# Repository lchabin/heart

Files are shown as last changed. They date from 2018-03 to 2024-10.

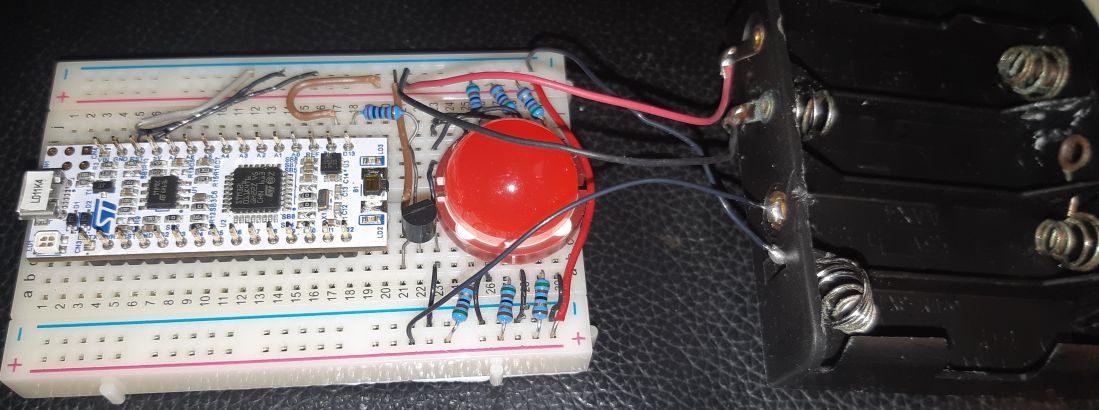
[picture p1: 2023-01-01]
doc/heart_beating.jpg

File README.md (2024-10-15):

# Red Beating Heart every Saint Valentin For the whole day. 
Proven 4 years autonomy with 2x2AA alcaline batteries.
On NUCLEO-L011K4

## Battery Autonomy
This design has been running non stop from March 17th 2018 to the end of 2022 on 4 AA alcaline batteries 
Configured to generate a pulse every hour (rather acceptable for the battery).
It has successfully generated heart beats every Saint Valentin of 2019,2020,2021,2022
The batteries were changed in Dec. 2022. 

Used this configuration in 2018:

$13h20m00s04w03m17d18y03600wkup

See below for explanations.

Used this configuration:

$17h14m00s06w12m31d22y03600wkup

## USING THE DESIGN WITH JUST THE NUCLEO BOARD : just to take a look, flash the board (program it) and make some tests

You can check the firmware and functionality before making the cicuit : 

Because it happens that PB3/D13 (GPIO of the nucleo board) also drives the green led of the nucleo board, you can test the functionality with the nucleo board as it is out of the factory. 
(no resistor, no transistor, no battery, with solder bridges SB14 and SB9 still closed, no big red led, no breadboard).

### Flashing (programming)
+ ensure no battery is connected
+ ensure SB14 and SB9 are closed
+ connect usb to a pc
+ flash using STM32CubeProg available from www.st.com 
(don't need the trusted package thing). 
+ You flash program the file MDK-ARM/heart/heart.hex
+ stop STM32CubeProg
### Settings and run
+ ensure no battery is connected
+ ensure SB14 is closed
+ start a terminal ('tera term' for instance) at 4800 bauds 
+ configure the terminal at 4800 bauds 
+ connect usb to a pc 
+ open connection to the new serial port in tera term
+ follow the instructions (displayed every 10 sec, with a led pulse)
Then it runs

## USING THE DESIGN ON BATTERY : the real deal
That's the only way to have it running for years.

### Prepare the NUCLEO board : REQUIRED ! 
See doc/open_sb14_sb9.png : open SB14 and SB9 solder bridges on the bottom on the nucleo board (voltage conflict, and reset).

From that moment, never connect anymore usb without the 3V battery holders connected to 3.3V first

Once SB9 is open, programming of the nucleo _may_ be a little more difficult (might fail more often), but i am not sure of that.  

### Flashing (programming) if not already done. RESPECT THAT SEQUENCE
+ ensure SB14 is open
+ connect battery to +3V3 pin and GND pin
+ connect usb to a pc
+ flash using STM32CubeProg available from www.st.com 
(don't need the trusted package thing).
+ You flash program the file heart.hex
+ stop STM32CubeProg
+ disconnect usb (clean fast disconnection)

### Settings and run. RESPECT THAT SEQUENCE
+ ensure SB14 and SB9 are open
+ start a terminal ('tera term' for instance) at 4800 bauds 
+ configure the terminal at 4800 bauds 
+ connect battery to +3V3 pin and GND pin
+ connect usb to a pc 
+ open connection to new serial port in tera term
+ follow instructions (displayed every 10 sec, with a led pulse)
+ disconnect usb (clean fast disconnection), voilà !

Once SB14 is open, Never connect usb without battery connected.

To restart the setting phase, you need to disconnect the battery then reconnect it (if a reset with the little push button on the side of the pcb is not enough).

## TRYING some tests

Examples (not in TESTING mode, nominal, heart.hex as on github)

### it is 1:20pm on thursday 15 march 2018

$13h20m00s04w03m15d18y00000wkup

+ will pulse on next saint valentin in 11 months, for 18 hours, then next year... 
+ one heart beat pulse every midnight
+ no wake up pulses

nota : monday is 01w

### it is 5:59pm on thursday 14 feb 2019

$17h59m00s04w02m14d19y00000wkup

+ will pulse on next saint valentin in one minute, for 18 hours, then next year.
+ one heart beat pulse every midnight
+ no wake up pulses

### it is 5:50pm on thursday 14 feb 2019

$17h50m00s04w02m14d19y03600wkup

+ will pulse on next saint valentin in ten minutes, for 18 hours, then next year.
+ one heart beat pulse every midnight
+ one wake up short pulse (150ms) every 3600 seconds  (just ok for the battery, help ensure it works)

## Touble shooting

if the red led flashes every 10 sec, that means that it is still waiting for a configuration to be given to it

using '03600wkup' in the config, helps check after one hour that it is really working 

## normal behaviour of the board

after a power on start up, 

+ the board does a 3 seconds fast pulse train
+ then it waits for the configuration information

Example of the text displayed:
```
You are in final target mode

Please write (or paste) the time and wake up delay. Don't use del,backspace because it is ignored
Example :
$21h24m00s05w03m09d18y00060wkup
Format : hour, minute, second, weekday, month, day of the month, year, wakeupEvery in seconds from 1 to 65535 (0 for no wake up). 01w == monday
$19h36m00s06w12m31d22y0360wkup
Setting time to $19h36m00s06w12m31d22y03600wkup
You can now disconnect usb.
```

+ just after configuration, it produces again a 3 seconds fast pulse train
+ there is then a 3 seconds delay, 
+ then, it produces again a 3 seconds fast pulse train
+ then it goes into deep sleep (standby) until the next wake up, midnight or saint valentin.

I would recommend that you disconnect USB during these 9 seconds of post configuration

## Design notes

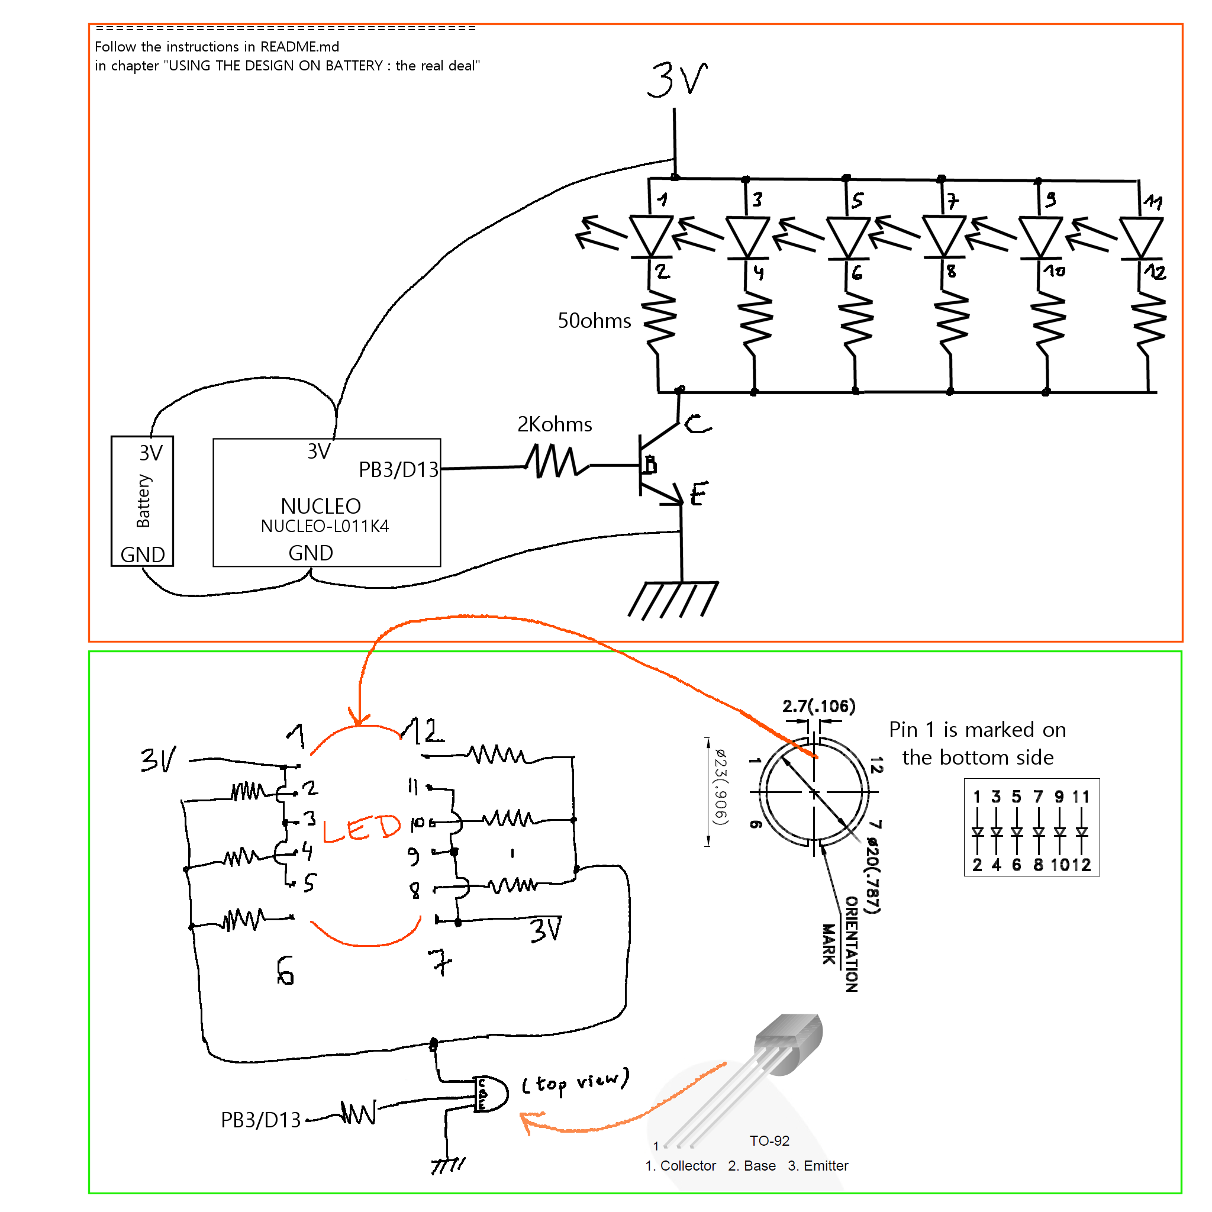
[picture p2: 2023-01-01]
doc/schematic.png

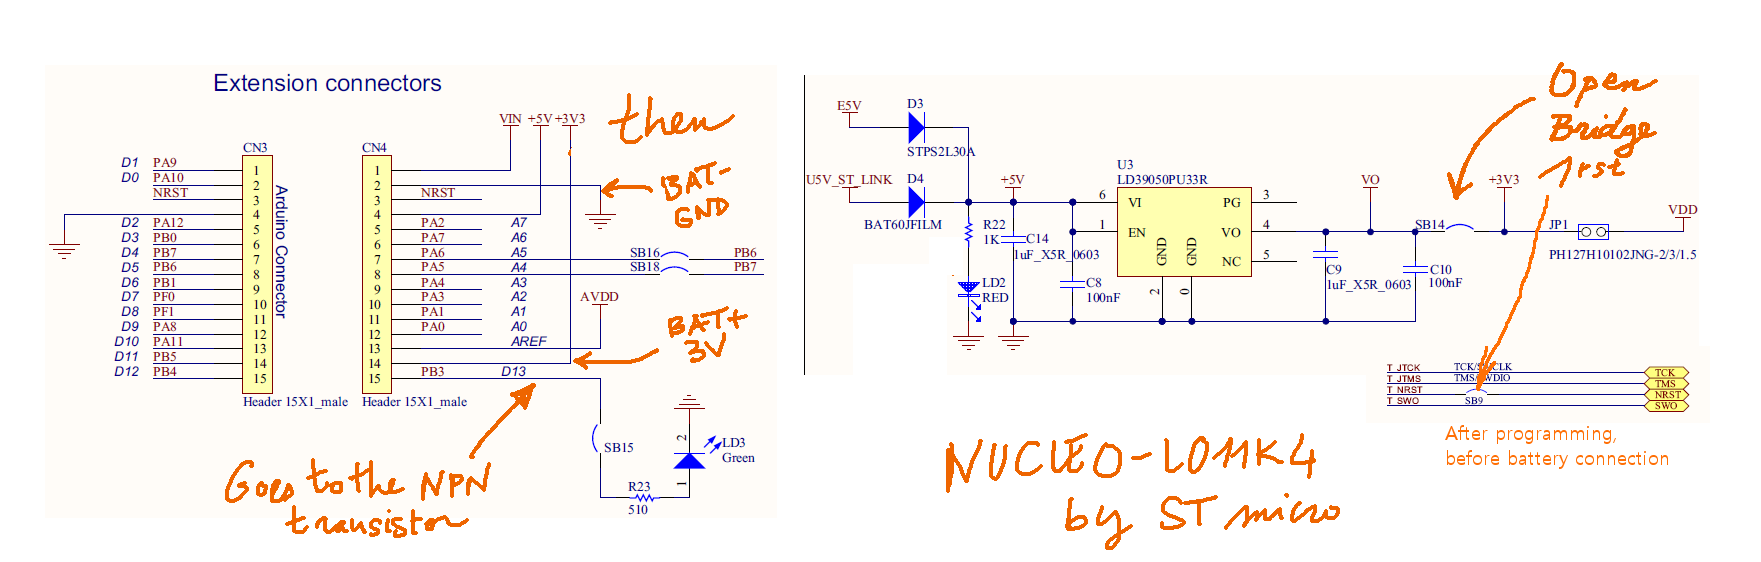
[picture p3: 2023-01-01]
doc/nucleo.png

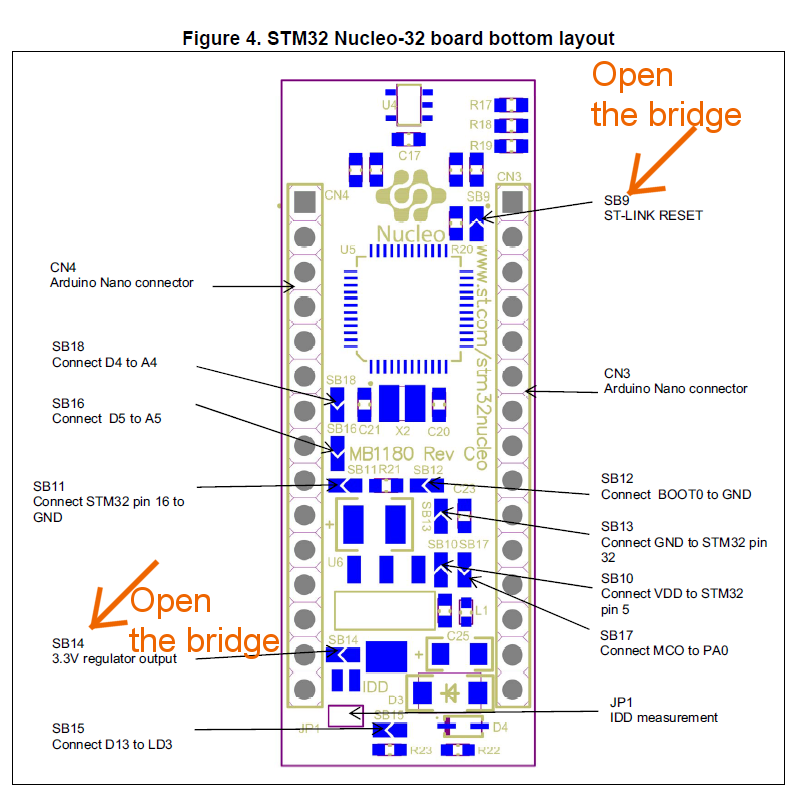
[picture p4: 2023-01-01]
doc/open_sb14_sb9.png

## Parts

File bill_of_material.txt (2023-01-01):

Bill of material 

USE ONLY ALCALINE 1.5V batteries, 
Get 4 batteries, new from the same pack. This is to ensure the same voltages because we are going to put them in parallel.

DO NOT USE ACCUMULATORS NiMH (1.2V), we need 1.5V during the programming phase else too large a voltage difference between 3.3V from USB and 2*Vbat

Farnell farnell.fr , farnell.com, www.newark.com references

03.530€ 1x 2146419 DLA/6SRD - LED, Basse puissance, Rouge, Traversant, 20mm, 20 mA, 1.85 V, 640 nm
03.230€ 1x 2395961 MCBB400 -  Carte prototypage, sans soudure, ABS (Acrylonitrile Butadiène Styrène), 8.3mm, 54.5mm x 83.5mm
01.200€ 2x 1702631 2463    -  Support batterie, AA x 2, à fils
11.000€ 1x 2535699 NUCLEO-L011K4 -  Carte de développement, STM32L011K4 MCU, Débogueur sur la carte, Compatible Arduino Nano
05.070€ 1x 817363  pack of four AA Alcaline Batteries 
00.148€ 1x 2453790 BC547BTF -  Transistor simple bipolaire (BJT), NPN, 45 V, 300 MHz, 500 mW, 100 mA, 200 hFE (per 5)
00.053€ 1x 2329911 TE CONNECTIVITY - Résistance traversante, 2 kohm, Série LR, 200 V, Couche métallique, Axial, 250 mW (per 10)
00.053€ 1x 2329951 TE CONNECTIVITY - Résistance traversante, 51 ohm, Série LR, 200 V, Couche métallique, Axial, 250 mW (per 10)

Some wire, for example if you have nothing (it is a rigid core, single conductor)
14.610€ 1 x 2290875 - 3050/1 WH005 -  Câble, Rigide, Hook Up, PVC (Chlorure de polyvinyle), Blanc, 24 AWG, 0.205 mm², 100 ft, 30.5 m
or much thinner and flexible, harder to strip and insert cause small:
14.500€ 1 x 1183994 - SPC00440A002 25M -  Câble, PTFE (Polytétrafluoroéthylène), Noir, 26 AWG, 0.128 mm², 82 ft, 25 m

One micro USB cable

6x 50 ohms resistors will limit current on each led to about 20mA
1x 2K ohms resistor from cpu PB3/D13 pin to base of transistor

an iron (just to open the SB14 and SB9 solder bridges on the nucleo board)

======================================
Justification for the values of the resistors

Current in the leds ? We want 0.02A current in each of the 6 leds total 0.120A, at ~1.85V.

Checking that the transistor will be able to drive the leds in good saturation
We have in datasheet NPN : hFE = 200.
Ibase = (3-0.6)/2000 = 0.0012A 
Icollector = 1.2mA*hFE = 0.240A. OK > 0.120A
OK

What resistor to put in series with the leds for that ?
BC547BTF Saturation voltage at 0.12A ~= 0.15v to 0.2v
which leads to a resistance for each led of R = U/I = (3-0.15-1.85)/0.02 = 50 ohms.

I think it would not be recommended to put all the leds in parallel with a single 8.3333 ohm resistor because of the variations in production, but it should rather work. Would still be below 1/4w
But that would make less wires.

======================================
Checking the firmware and functionality before assembly on the breadboard

Because it happens that PB3/D13 also drives the green led of the nucleo board, you can test the functionality with the nucleo board as it is out of the factory. 
(no resistor, no transistor, no battery, with SB14 and SB9 still closed, no big led, no breadboard).

======================================
To build the circuit with the breadboard, the components and wires:
See doc/schematic.png
See doc/nucleo.png
See doc/open_sb14_sb9.png
Ask if you have no idea how to do that.

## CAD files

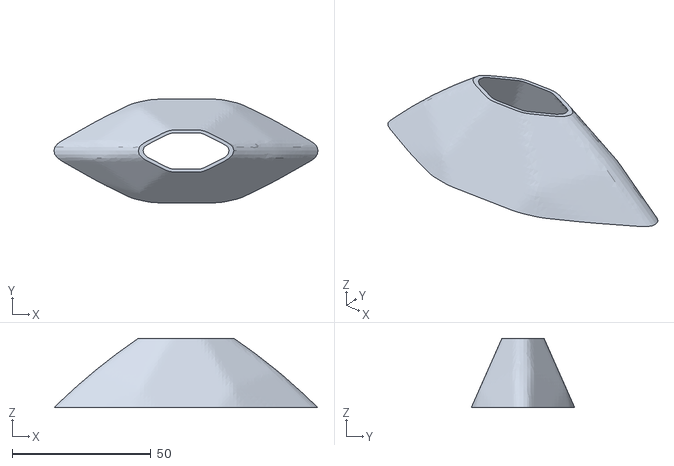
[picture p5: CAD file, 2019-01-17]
3d/support_pet_coeur.stl
95.3 x 37.4 x 25.0

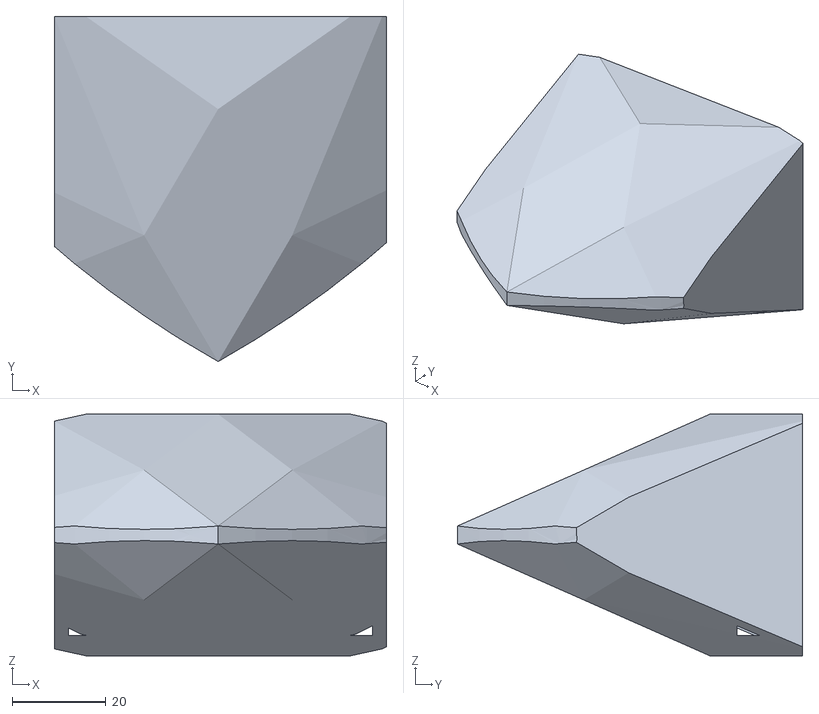
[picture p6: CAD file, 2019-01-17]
3d/support_elec.stl
71.0 x 73.8 x 51.7

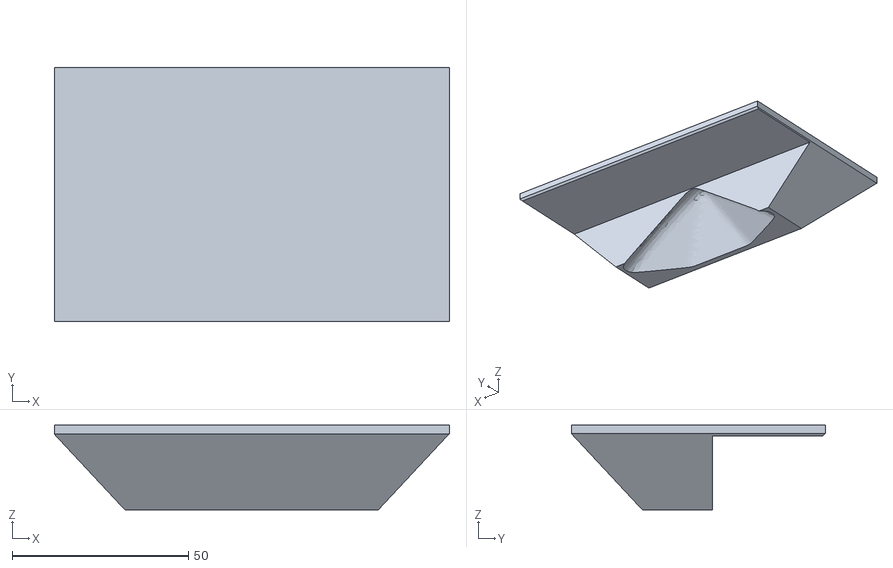
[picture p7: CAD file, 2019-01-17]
3d/support_coeur.stl
112.0 x 72.0 x 24.0

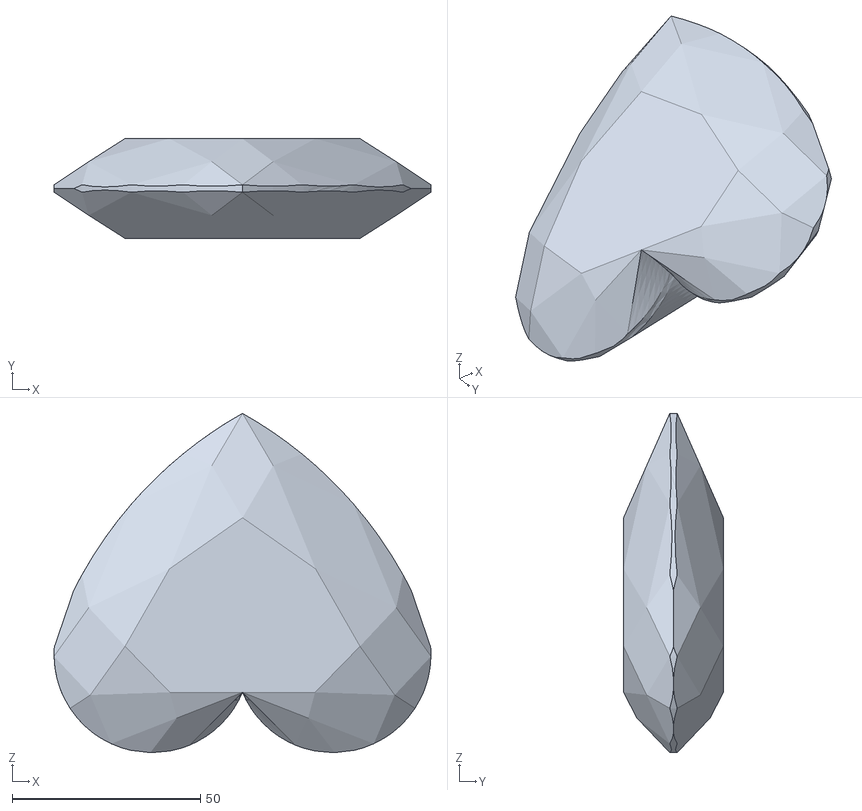
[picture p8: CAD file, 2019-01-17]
3d/Heart-shaped-Gem.stl
100.0 x 26.5 x 90.0

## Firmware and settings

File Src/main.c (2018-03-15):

/**
  ******************************************************************************
  * @file           : main.c
  * @brief          : Main program body
  ******************************************************************************
  ** This notice applies to any and all portions of this file
  * that are not between comment pairs USER CODE BEGIN and
  * USER CODE END. Other portions of this file, whether 
  * inserted by the user or by software development tools
  * are owned by their respective copyright owners.
  *
  * COPYRIGHT(c) 2018 STMicroelectronics
  *
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
  ******************************************************************************
  */
/* Includes ------------------------------------------------------------------*/
#include "main.h"
#include "stm32l0xx_hal.h"

/* USER CODE BEGIN Includes */
#include "stm32l0xx_hal_rtc.h"
#include "led.h"
#include "set_time.h"
/* USER CODE END Includes */

RTC_HandleTypeDef hrtc;

UART_HandleTypeDef huart2;

/* USER CODE BEGIN PV */

/* USER CODE END PV */

void SystemClock_Config(void);
static void MX_GPIO_Init(void);

/* USER CODE BEGIN PFP */

/* USER CODE END PFP */

/* USER CODE BEGIN 0 */

// Even with a quartz 32.768Khz, the clock will drift a lot over the years
// You might measure luminosity (with some electronics and code) and steer RTC to follow the daylight to compensate drift for years
// your code here
// Will be called every "wakeupEvery"
// but I think that 20ppm is enough : only 1.75 hours shift in 10 years... OK.
// 24h*365.25*10*20e-6 = 1.75h
void wakeupStep(void)
{
		ledOn();
		HAL_Delay(150);
		ledOff();	
}

void daylyStep(void)
{
		ledPulse();
}

// TESTING can be defined in the project properties.
// Remove it when done.
// Run Beating Heart for ... seconds
#ifdef TESTING
#define SECONDS_BEATING_HEART  120 
#define RTC_MONTH_SELECTED RTC_MONTH_MARCH
#else
// beating heart for 18 hours :  3600*18
#define SECONDS_BEATING_HEART  (3600*18)
// saint valentin is in february
#define RTC_MONTH_SELECTED RTC_MONTH_FEBRUARY
#endif

void saintValentin(void)
{
	for (int i=0;i<SECONDS_BEATING_HEART ;i++)
		heartBeatOneSecond();
}

uint8_t g_saintValentin;
uint8_t g_wakeUp;
uint8_t g_dailyAlarm;

// Default config that will be written if nothing sent after 100secs on the serial port
// Useful in dev phase, we don't need to have a complex setup 
// But when on battery 3V, will need to use the serial port 
uint8_t clock_time[] = "23h59m00s06w03m09d18y00120wkup"; // 30+1 for a 0x00 terminated char inserted by the compilator, but not required to have one

/* USER CODE END 0 */

/**
  * @brief  The application entry point.
  *
  * @retval None
  */
int main(void)
{
  /* USER CODE BEGIN 1 */
	uint32_t tickstart;
	RTC_DateTypeDef sDate1;
	RTC_DateTypeDef sDate2;
	uint8_t outOfStandby;
  /* USER CODE END 1 */

  /* MCU Configuration----------------------------------------------------------*/

  /* Reset of all peripherals, Initializes the Flash interface and the Systick. */
  HAL_Init();

  /* USER CODE BEGIN Init */
// WE DONT CALL MX_RTC_Init(), we run our own code
  /* USER CODE END Init */

  /* Configure the system clock */
  SystemClock_Config();

  /* Initialize all configured peripherals */
  MX_GPIO_Init();
  /* USER CODE BEGIN 2 */
	
	HAL_PWREx_EnableLowPowerRunMode();
	
	hrtc.Instance = RTC;
	
	if (PWR->CSR & PWR_CSR_SBF) 
	{
		outOfStandby = true;	// We come back from standby
		PWR->CR |= PWR_CR_CSBF; // reset bit.  
	}
	else
		outOfStandby = false;

  /* USER CODE END 2 */

  /* Infinite loop */
  /* USER CODE BEGIN WHILE */
  while (1) 
  {
		g_saintValentin = false; // XXXXXX  Put a breakpoint here, debug, run, breakpoint, reset, remove breakpoint then run to debug the setup code 
		g_wakeUp = false;
		g_dailyAlarm = false;

		// Identify the cause of Interrupt, and reset int flag 
		
		if (__HAL_RTC_WAKEUPTIMER_GET_FLAG(&hrtc,RTC_ISR_WUTF)) // by WAKE UP
		{
			/* Disable the write protection for RTC registers */
			__HAL_RTC_WRITEPROTECTION_DISABLE(&hrtc);
			__HAL_RTC_WAKEUPTIMER_DISABLE(&hrtc);
			__HAL_RTC_WAKEUPTIMER_CLEAR_FLAG(&hrtc, RTC_FLAG_WUTF);
			tickstart = HAL_GetTick();
			/* Wait till RTC ALRAWF flag is set and if Time out is reached exit */
			while(__HAL_RTC_WAKEUPTIMER_GET_FLAG(&hrtc, RTC_ISR_WUTWF) == RESET)
			{
				if((HAL_GetTick() - tickstart ) > RTC_TIMEOUT_VALUE)
				{
					/* Enable the write protection for RTC registers */
					__HAL_RTC_WRITEPROTECTION_ENABLE(&hrtc);
					crash(1);
				}
			}
			__HAL_RTC_WAKEUPTIMER_ENABLE(&hrtc);
			/* Enable the write protection for RTC registers */
			__HAL_RTC_WRITEPROTECTION_ENABLE(&hrtc);
			
			g_wakeUp = true;
		}

		// Identify the cause of Interrupt, and reset int flag 
		
		if (__HAL_RTC_ALARM_GET_FLAG(&hrtc,RTC_ISR_ALRAF)) // By ALARM A
		{
				/* Disable the write protection for RTC registers */
				__HAL_RTC_WRITEPROTECTION_DISABLE(&hrtc);
				__HAL_RTC_ALARMA_DISABLE(&hrtc);
				__HAL_RTC_ALARM_CLEAR_FLAG(&hrtc, RTC_FLAG_ALRAF);
				tickstart = HAL_GetTick();
				/* Wait till RTC ALRAWF flag is set and if Time out is reached exit */
				while(__HAL_RTC_ALARM_GET_FLAG(&hrtc, RTC_FLAG_ALRAWF) == RESET)
				{
					if((HAL_GetTick() - tickstart ) > RTC_TIMEOUT_VALUE)
					{
						/* Enable the write protection for RTC registers */
						__HAL_RTC_WRITEPROTECTION_ENABLE(&hrtc);					
						crash(2);
					}
				}
				__HAL_RTC_ALARMA_ENABLE(&hrtc);
				/* Enable the write protection for RTC registers */
				__HAL_RTC_WRITEPROTECTION_ENABLE(&hrtc);

// APB1 Clock = 131Khz < 7*32.768Khz
/*
To be able to read the RTC calendar register when the APB1 clock frequency is less than
seven times the RTC clock frequency (7*RTCLCK), the software must read the calendar
time and date registers twice.
If the second read of the RTC_TR gives the same result as the first read, this ensures that
the data is correct. Otherwise a third read access must be done.
*/		
				
			HAL_RTC_GetDate(&hrtc, &sDate1, RTC_FORMAT_BCD);
			HAL_RTC_GetDate(&hrtc, &sDate2, RTC_FORMAT_BCD);
			if (sDate1.Month!=sDate2.Month)
			{
				HAL_RTC_GetDate(&hrtc, &sDate1, RTC_FORMAT_BCD);
			}
				
			if (sDate1.Month==RTC_MONTH_SELECTED)
				g_saintValentin = true;
		}

		// Identify the cause of Interrupt, and reset int flag 
		
		if (__HAL_RTC_ALARM_GET_FLAG(&hrtc,RTC_ISR_ALRBF)) // By ALARM B
		{
				/* Disable the write protection for RTC registers */
				__HAL_RTC_WRITEPROTECTION_DISABLE(&hrtc);
				__HAL_RTC_ALARMB_DISABLE(&hrtc);
				__HAL_RTC_ALARM_CLEAR_FLAG(&hrtc, RTC_FLAG_ALRBF);
				tickstart = HAL_GetTick();
				/* Wait till RTC ALRBWF flag is set and if Time out is reached exit */
				while(__HAL_RTC_ALARM_GET_FLAG(&hrtc, RTC_FLAG_ALRBWF) == RESET)
				{
					if((HAL_GetTick() - tickstart ) > RTC_TIMEOUT_VALUE)
					{
						/* Enable the write protection for RTC registers */
						__HAL_RTC_WRITEPROTECTION_ENABLE(&hrtc);					
						crash(9);
					}
				}
				__HAL_RTC_ALARMB_ENABLE(&hrtc);
				/* Enable the write protection for RTC registers */
				__HAL_RTC_WRITEPROTECTION_ENABLE(&hrtc);

				g_dailyAlarm = true;
		}
		
		
		
		if (outOfStandby) // We come back from standby
		{
			// Process interrupts
			if (g_wakeUp)
			{
				wakeupStep();
			}
			if (g_dailyAlarm)
			{
				daylyStep();
			}
			if (g_saintValentin)
			{
				saintValentin();
			}
		}
		else // this is a power on startup : setup code : get time by serial port or set it to some default value (for tests)
		{ 
			pulseTrain3s();  
			HAL_Delay(3000);

			getConfigByComPort(clock_time,sizeof(clock_time)-1);
			
			__HAL_RTC_WRITEPROTECTION_DISABLE(&hrtc);
			__HAL_RTC_WAKEUPTIMER_DISABLE(&hrtc); // necessary  ? 
			__HAL_RTC_ALARMA_DISABLE(&hrtc);
			__HAL_RTC_ALARMB_DISABLE(&hrtc);
			__HAL_RTC_WRITEPROTECTION_ENABLE(&hrtc);

			RTC_Init_Time_and_Date(clock_time);
			RTC_Set_Enable_WakeUp_AlarmAB(clock_time);
			pulseTrain3s();
			HAL_Delay(3000);
			pulseTrain3s();
		}
/*
	DBGMCU->CR |= DBGMCU_CR_DBG_STOP;
	DBGMCU->CR |= DBGMCU_CR_DBG_STANDBY;
*/
	
	HAL_PWREx_EnableFastWakeUp();
	HAL_PWREx_EnableUltraLowPower();
	HAL_PWR_EnterSTANDBYMode();	 // on exit from standby, the CPU will reset
	// but if a new interrupt is again pending, in that case we don't enter standby mode...
	// this while loop saves us, we process again that new interrupt. At least we should reset the flag
	// this can happen if during a long saintValentin() call, the wakeup timer triggers.
		
  /* USER CODE END WHILE */

  /* USER CODE BEGIN 3 */
  }
  /* USER CODE END 3 */

}

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


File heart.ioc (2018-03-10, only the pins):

Mcu.UserName=STM32L011K3Tx
PA13.Signal=SYS_SWDIO
PA14.Signal=SYS_SWCLK
PA15.Signal=USART2_RX
PA2.Signal=USART2_TX
PB3.GPIO_Label=LED
PB3.Signal=GPIO_Output
PC14-OSC32_IN.Signal=RCC_OSC32_IN
PC15-OSC32_OUT.Signal=RCC_OSC32_OUT

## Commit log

2018-03-07 $FW : commit with RTC functional, load of current time in RTC by serial port on power on. Then goes to standby until cyclic wake up or alarm A
2018-03-09 $FW : to also read correctly the wakeup delay by the comport. One more pending issue it seems after alarma processing
    [main.c, set_time.c]
2018-03-10 $FW lot a refactoring and comments. Fix : avoid double alarma trigger. Clock Time Set more user friendly. com port at 4800 bauds, low power run. Tested. PowerConsumption Calculator says it should run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
    [heart.ioc, led.c, main.c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]
2018-03-10 $FW : added alarmb for a daily pulse at midnight. To be able to track clock drift and be able to check that it is still alive. Move gpio pin for the led. $DOC : added to readme
    [heart.ioc, main.c, set_time.c]
2018-03-10 $DOC schematic, bill of material and user and manual
2019-01-17 updated docs
    [Heart-shaped-Gem.stl, heart.fzz, heart_using_dla6srd.fzz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]
2022-12-27 doc , bom as a separate doc for more clarity
2023-01-01 You actually really need to open SB9 when running on battery.

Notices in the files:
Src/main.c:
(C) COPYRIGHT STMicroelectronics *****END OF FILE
